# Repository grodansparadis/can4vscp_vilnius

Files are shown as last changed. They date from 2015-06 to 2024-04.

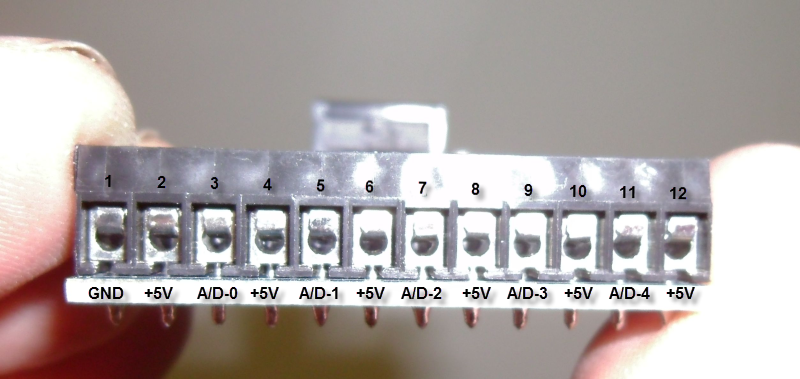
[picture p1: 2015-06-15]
manual/images/termination_block.png

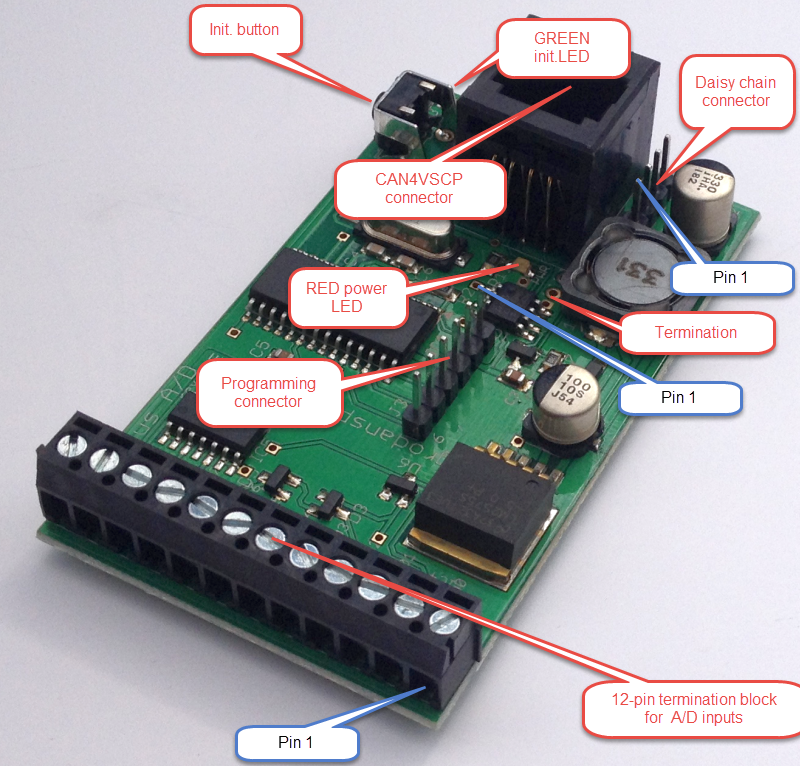
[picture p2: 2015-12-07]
images/vilnius_components.png

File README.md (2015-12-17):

<h1>Vilnius A/D module</h1>



Vilnius A/D module is a CAN4VSCP based module that have four 10-bit A/D channels for 0-5V or 0-10V and also have two 5V I/O channels that can be set as inputs or outputs. General use is to read analog values and as all other VSCP modules you can get the readings reported automatically with a user specified period.

It is also possible to report A/D readings as a VSCP measurement linearized as a floating point value from the formula

measurement = k * A/D-value + m

where k and m are configurable 32-bit floating point constants. You have full control of which event is sent and which unit is used.

This means you can send out any A/D reading as a real unit such as voltage, temperature or in any other SI specified unit.

You can also assign alarm limits so that alarm events are sent when the level goes above a certain value or below a certain value.

Two I/O channels are available. Both can individually be set as inputs or outputs. ON/OFF or TurnOn/TurnOff events can be sent out when I/O change state.

The module can be attached to a standard DIN Rail or be mounted directly on a wall. The mounting enclosures are ordered as separate options when the module is ordered.

The module fully adopts to the VSCP CAN4VSCP specification and can be powered directly over the bus cable with a good 9-28V DC power source. This means there is no need for a separate power cable. VSCP CAN modules are designed to work on a VSCP4CAN bus which use ordinary RJ-45 connectors or use the daisy chain pinhead which can be used to connect modules that are mounted close to each other. For the bus a CAT5 or better twisted pair cable is used. Bus length can have a total length of 500 meters with drops of maximum 24 meters length (up to a total of 120 meters). As for all VSCP4CAN modules the communication speed is fixed at 125 kbps.

All VSCP modules contains information of there own setup, manual, hardware version, manufacturer etc. When VSCP modules are started up they have a default functionality that often is all that is needed to get a working setup. If the module have something to report it will send you an event and if it is setup to react on a certain type of event it will do it's work when you send event(s) to it. It does not need to be harder then that. 

<hr>

This project is part of the <a href="http://www.vscp.org">VSCP (Very Simple Control Protocol) project</a>. 

<hr>

This project is licensed under the 
<a href="http://creativecommons.org/licenses/by-nc-sa/3.0/">Creative Commons open source license Attribution-NonCommercial-ShareAlike 3.0 Unported</a>. 
Other license options are available by conacting <a href="malto:info@grodansparadis.com">Paradis of the Frog AB</a>

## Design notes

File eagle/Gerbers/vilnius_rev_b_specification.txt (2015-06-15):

Ake Hedman
Grodans Paradis AB

Date:				2014-06-18
Part Number: 		Vilnius
Number of boards: 	120
Number of layers: 	2 
Material: 			FR4
Final Thickness:	1.6 mm
Final copper:		1/1oz
Surface treatment: 	ENIG
Unit Size:			72 x 42 mm
Panel Size:			154*126 mm
Unit/panel:			6
Solder Mask:		Green
Silk Screen: 		White	
Outline Profile:	CNC Routing + V-cut
X-out Allowed:		1
Stencil needed:		yes
Gerber layer for Stencil: Component Cream (pmc)

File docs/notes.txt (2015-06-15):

Vilnius notes
=============

Registers
=========
00	Zone
01	Subzone
02	Control register A/D 0
		Bit 0 - Enable
		Bit 1 - Enable event when above level
		Bit 2 - Enable event when below level
		Bit 3 - 
		Bit 4 - 
		Bit 5 - 
		Bit 6 -
		Bit 7 -  	
03	Control register A/D 1
04	Control register A/D 2
05	Control register A/D 3
06	Control register A/D 4

07	Level high for channel 0 MSB   (0-10V * 10000)
08	Level high for channel 0 LSB
09	Level high for channel 1 MSB
0A	Level high for channel 1 LSB
0B	Level high for channel 2 MSB
0C	Level high for channel 2 LSB
0D	Level high for channel 3 MSB
0E	Level high for channel 3 LSB
0F	Level high for channel 4 MSB
10	Level high for channel 5 LSB

11	Level low for channel 0 MSB   (0-10V * 10000)
12	Level low for channel 0 LSB
13	Level low for channel 1 MSB
14	Level low for channel 1 LSB
15	Level low for channel 2 MSB
16	Level low for channel 2 LSB
17	Level low for channel 3 MSB
18	Level low for channel 3 LSB
19	Level low for channel 4 MSB
1A	Level low for channel 5 LSB

1B	Absolute low for channel 0 MSB   (0-10V * 10000)
1C	Absolute low for channel 0 LSB
1D	Absolute low for channel 1 MSB
1E	Absolute low for channel 1 LSB
1F	Absolute low for channel 2 MSB
20	Absolute low for channel 2 LSB
21	Absolute low for channel 3 MSB
22	Absolute low for channel 3 LSB
23	Absolute low for channel 4 MSB
24	Absolute low for channel 5 LSB

25	Absolute high for channel 0 MSB   (0-10V * 10000)
26	Absolute high for channel 0 LSB
27	Absolute high for channel 1 MSB
28	Absolute high for channel 1 LSB
29	Absolute high for channel 2 MSB
2A	Absolute high for channel 2 LSB
2B	Absolute high for channel 3 MSB
2C	Absolute high for channel 3 LSB
2D	Absolute high for channel 4 MSB
2E	Absolute high for channel 5 LSB

A/D stream frequency
Event above level
Event below level
hysteresis.

Actions
=======
0	NOOP
1	Send state. (for sync)

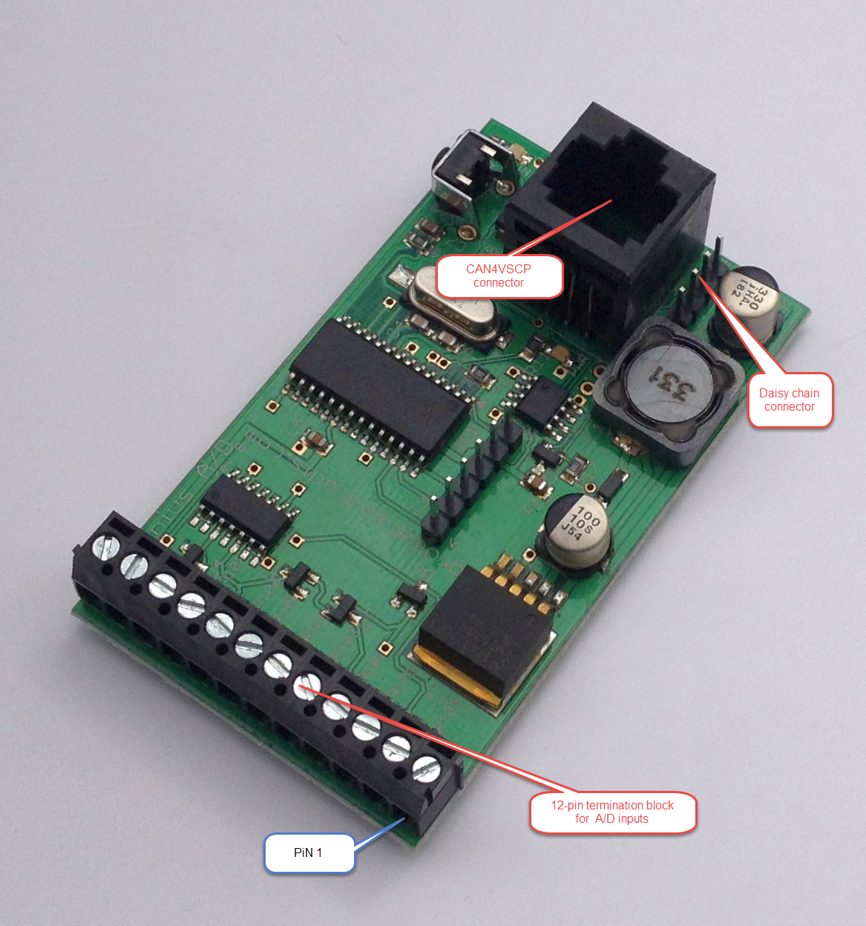
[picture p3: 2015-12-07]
images/vilnius_connectors.png

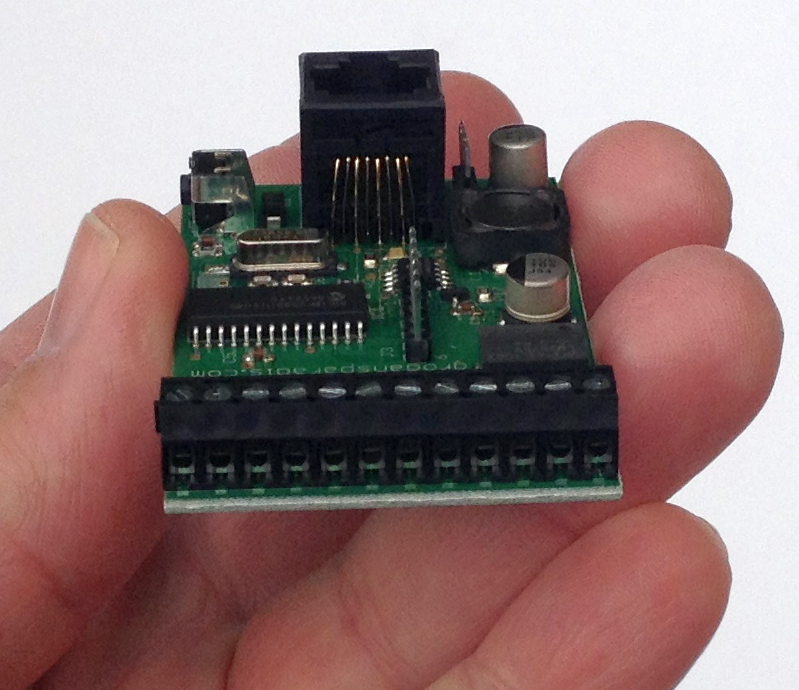
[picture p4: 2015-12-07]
images/vilnius13.png

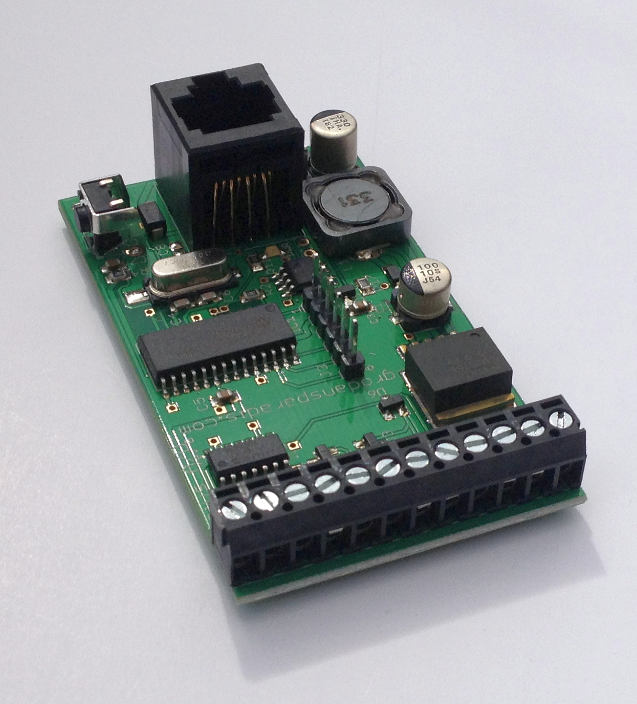
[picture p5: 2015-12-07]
images/vilnius3.png

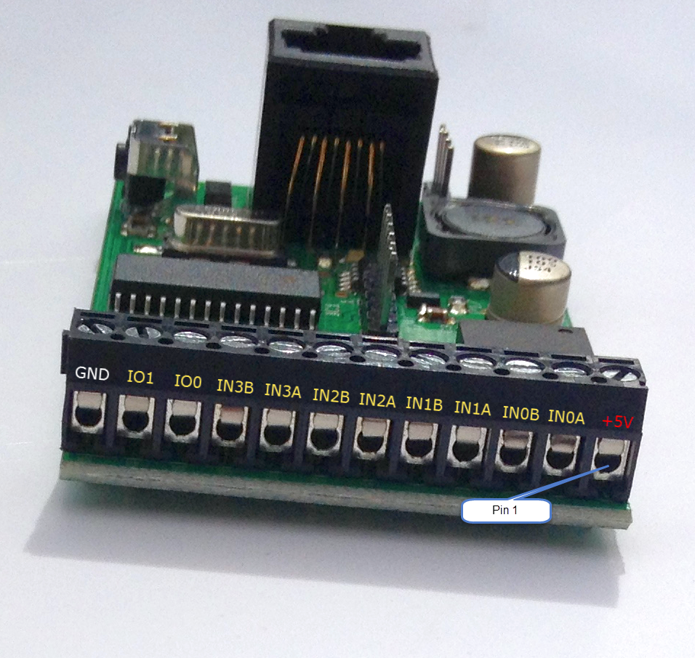
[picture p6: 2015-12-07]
images/vilnius_termination_block.png

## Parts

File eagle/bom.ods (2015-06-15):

Partlis | t exported from | C:/Users/akhe/Docu | ments/develop | ment/hardware_zeus/can4vscp/vilnius_Analog2Digita | l/eagle/vilnius_rev_a.s | ch at 201 | 1-10-04 12:57:53
Part | Value | Device | Package | Description | Description | Supplier | Partnumber | Price
1N5819 | S1D | DIODE-SMB | SMB | DIODE | Protection diod | Digikey | 1N5819HW-FDICT-ND | 3,84
C1 | 100uF | CPOL-EUD | PANASONIC_D | POLARIZED CAPACITOR, European symbol | Elektrolytkondensator | Digikey | PCE3951CT-ND | 5,04
C2 | 330uF | CPOL-EUD | PANASONIC_D | POLARIZED CAPACITOR, European symbol | Elektrolytkondensator | Digikey | PCE4164CT-ND | 4,4
C3 | 100nF | CNP-0805 | 805 | NON-POLARIZED CAP | Avstörningskondensator | Bejoken | 522526 | 0,07
C4 | 15pF | C-EUC0805 | C0805 | CAPACITOR, European symbol | Kondensator | Bejoken | 522419 | 0,11
C5 | 0.1uF | C-EUC0805 | C0805 | CAPACITOR, European symbol | Avstörningskondensator | Bejoken | 522526 | 0,07
C6 | 15pF | C-EUC0805 | C0805 | CAPACITOR, European symbol | Kondensator | Bejoken | 522419 | 0,11
C7 | 0.1uF | C-EUC0805 | C0805 | CAPACITOR, European symbol | Avstörningskondensator | Bejoken | 522526 | 0,07
D1 | S1D | DIODE-SMB | SMB | DIODE | Protection diod | Digikey | 1N5819HW-FDICT-ND | 3,84
D2 | NUP2105L | DIODE-2CA|ACSOT23 | SOT23@1 | Dual DIODE Cathode-Anode|Anode-Cathode | Tansient protection | Digikey | NUP2105LT1GOSCT-ND | 4
D3 | BAT54 | BAV199 | SOT23 | DIODE | Skyddsdiod | Bejoken | 177820 | 0,75
D4 | BAT54 | BAV199 | SOT23 | DIODE | Skyddsdiod | Bejoken | 177820 | 0,75
D5 | BAT54 | BAV199 | SOT23 | DIODE | Skyddsdiod | Bejoken | 177820 | 0,75
D6 | BAT54 | BAV199 | SOT23 | DIODE | Skyddsdiod | Bejoken | 177820 | 0,75
IC1 | PIC18F2580 | PIC18LF252-I/SO | SO28 | 18F252, 28 pin, 32Kb prog, 1536 data, 256 EEPROM | Processor | Digikey | PIC18F2580-I/SO-ND | 60,96
IC3 | MCP2551SN | MCP2551SN | SO-08 | High Speed CAN tranceiver | CAN tranceiver | Digikey | MCP2551-I/SN-ND | 8,96
IC4 | LM2575S | LM2575S | TO263-5 | National Semiconductor 1.0A "Simple Switcher"(c) | Simpleswitcher | Digikey | LM2575S-3.3/NOPB-ND | 23,76
IC5 | MCP604 | 4AMP_P4+11D | SO14 | OP AMP | Opamp | Digikey | MCP6044-I/SL-ND | 11,14
J1 | OSTTE-12 | OSTTE-12 | PINHEAD-12 |  | Terminal Block ' 12 | Digikey | ED2737-nd | 11,68
J2 | A00-108-220-450 | A00-108-220-450 | RJ-45 |  | RJ-45 connector | Digikey | 151-1099-nd | 5,6
J3 |  | MA06-1 | MA06-1 | PIN HEADER | Enkel stiftlist | Digikey | SAM1035-50-ND | 0,33
J4 |  | MA04-1 | MA04-1 | PIN HEADER | Enkel stiftlist | Digikey | SAM1035-50-ND | 0,33
L1 | 330 uH | DO3316P | DO3316P | COILCRAFT | Drossel 330u | Digikey | 553-1514-1-nd | 10,24
LED1 |  | LEDCHIP-LED0805 | CHIP-LED0805 | LED | Green LED | Digikey | 475-1410-1-nd | 0,88
LED9 |  | LEDCHIP-LED0805 | CHIP-LED0805 | LED | Green LED | Digikey | 475-1410-1-nd | 0,88
Q1 | 10 MHz | HC-49S | 9C | Digikey 887-1050-1-nd | 10 MHz Crystal | Digikey | 887-1050-1-d | 4,24
R2 | 10K | R-EU_R0805 | R0805 | RESISTOR, European symbol | Resistor | Bejoken | 454676 | 0,01
R3 | 1K | R-EU_R0805 | R0805 | RESISTOR, European symbol | Resistor | Bejoken | 454650 | 0,01
R4 | 10K | R-EU_R0805 | R0805 | RESISTOR, European symbol | Resistor | Bejoken | 454676 | 0,01
R11 | 1K | R-EU_R0805 | R0805 | RESISTOR, European symbol | Resistor | Bejoken | 454650 | 0,01
R100 | 10K | R-EU_R0805 | R0805 | RESISTOR, European symbol | Resistor | Bejoken | 454676 | 0,01
R101 | 10K | R-EU_R0805 | R0805 | RESISTOR, European symbol | Resistor | Bejoken | 454676 | 0,01
R102 | 10K | R-EU_R0805 | R0805 | RESISTOR, European symbol | Resistor | Bejoken | 454676 | 0,01
R103 | 10K | R-EU_R0805 | R0805 | RESISTOR, European symbol | Resistor | Bejoken | 454676 | 0,01
R104 | 10K | R-EU_R0805 | R0805 | RESISTOR, European symbol | Resistor | Bejoken | 454676 | 0,01
R105 | 10K | R-EU_R0805 | R0805 | RESISTOR, European symbol | Resistor | Bejoken | 454676 | 0,01
R106 | 10K | R-EU_R0805 | R0805 | RESISTOR, European symbol | Resistor | Bejoken | 454676 | 0,01
R107 | 10K | R-EU_R0805 | R0805 | RESISTOR, European symbol | Resistor | Bejoken | 454676 | 0,01
S1 |  | 31-XX | B3F-31XX | OMRON SWITCH | Init switch | Elfa | 35-677-65 | 2,89
 |  |  |  |  |  |  |  | 166,56

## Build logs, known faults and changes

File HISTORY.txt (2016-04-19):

Vilnius A/D converter module
============================

2016-04-19 AKHE - RA4 set to input to prevent collision with VCAP circuits in
                  PIC18F2580. Brown out raised to maximum (3V & 4.6V). Valuable                    input from Anders Forsgren, AJE Electronics AB.
2016-04-11 AKHE - vscp_getMatrixInfo nw use the pointer supplied by the framework.
2016-04-04 AKHE - Changed value of C14 to 10uF
2016-03-23 AKHE - Version 1.0.3------------------------------------------------
2016-03-23 AKHE - Adopter to VSCP firmware 1.6.1
2016-03-08 AKHE - Adopted to 1.6 firmware. Adopted for PIC18F26K80.
2015-11-15 AKHE - Started development

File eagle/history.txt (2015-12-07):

Vilnius
=======

2015-12-07 - AKHE Added missing power and ground on IC5.
2015-12-07 - AKHE Named ports.
2015-11-14 - AKHE VCAP decoupled from VCC
2015-11-14 - Rev C
2014-06-19 - AKHE Fixed dimensions
2014-06-18 - AKHE Away to factory
2013-06-04 - AKHE Added power to missing pin 6 capacitor.
2011-12-20 - AKHE Added termination resistor. Leave unpopulated.
2011-11-17 - AKHE Added 1uF capacitor on uP pin 6 forPIC18F66K80 compatibility
2011-11-15 - AKHE Move L1 so it fits on the board.
2011-11-10 - AKHE Packages for D1/D2 updatet to SOD123 from SMDB
2011-11-10 - AKHE CANH should be on pin 4 of RJ-45
2011-11-02 - AKHE Kontaktlist uppdaterad. Hål var 0.9 och för trånga. Nu 1.2 istället.

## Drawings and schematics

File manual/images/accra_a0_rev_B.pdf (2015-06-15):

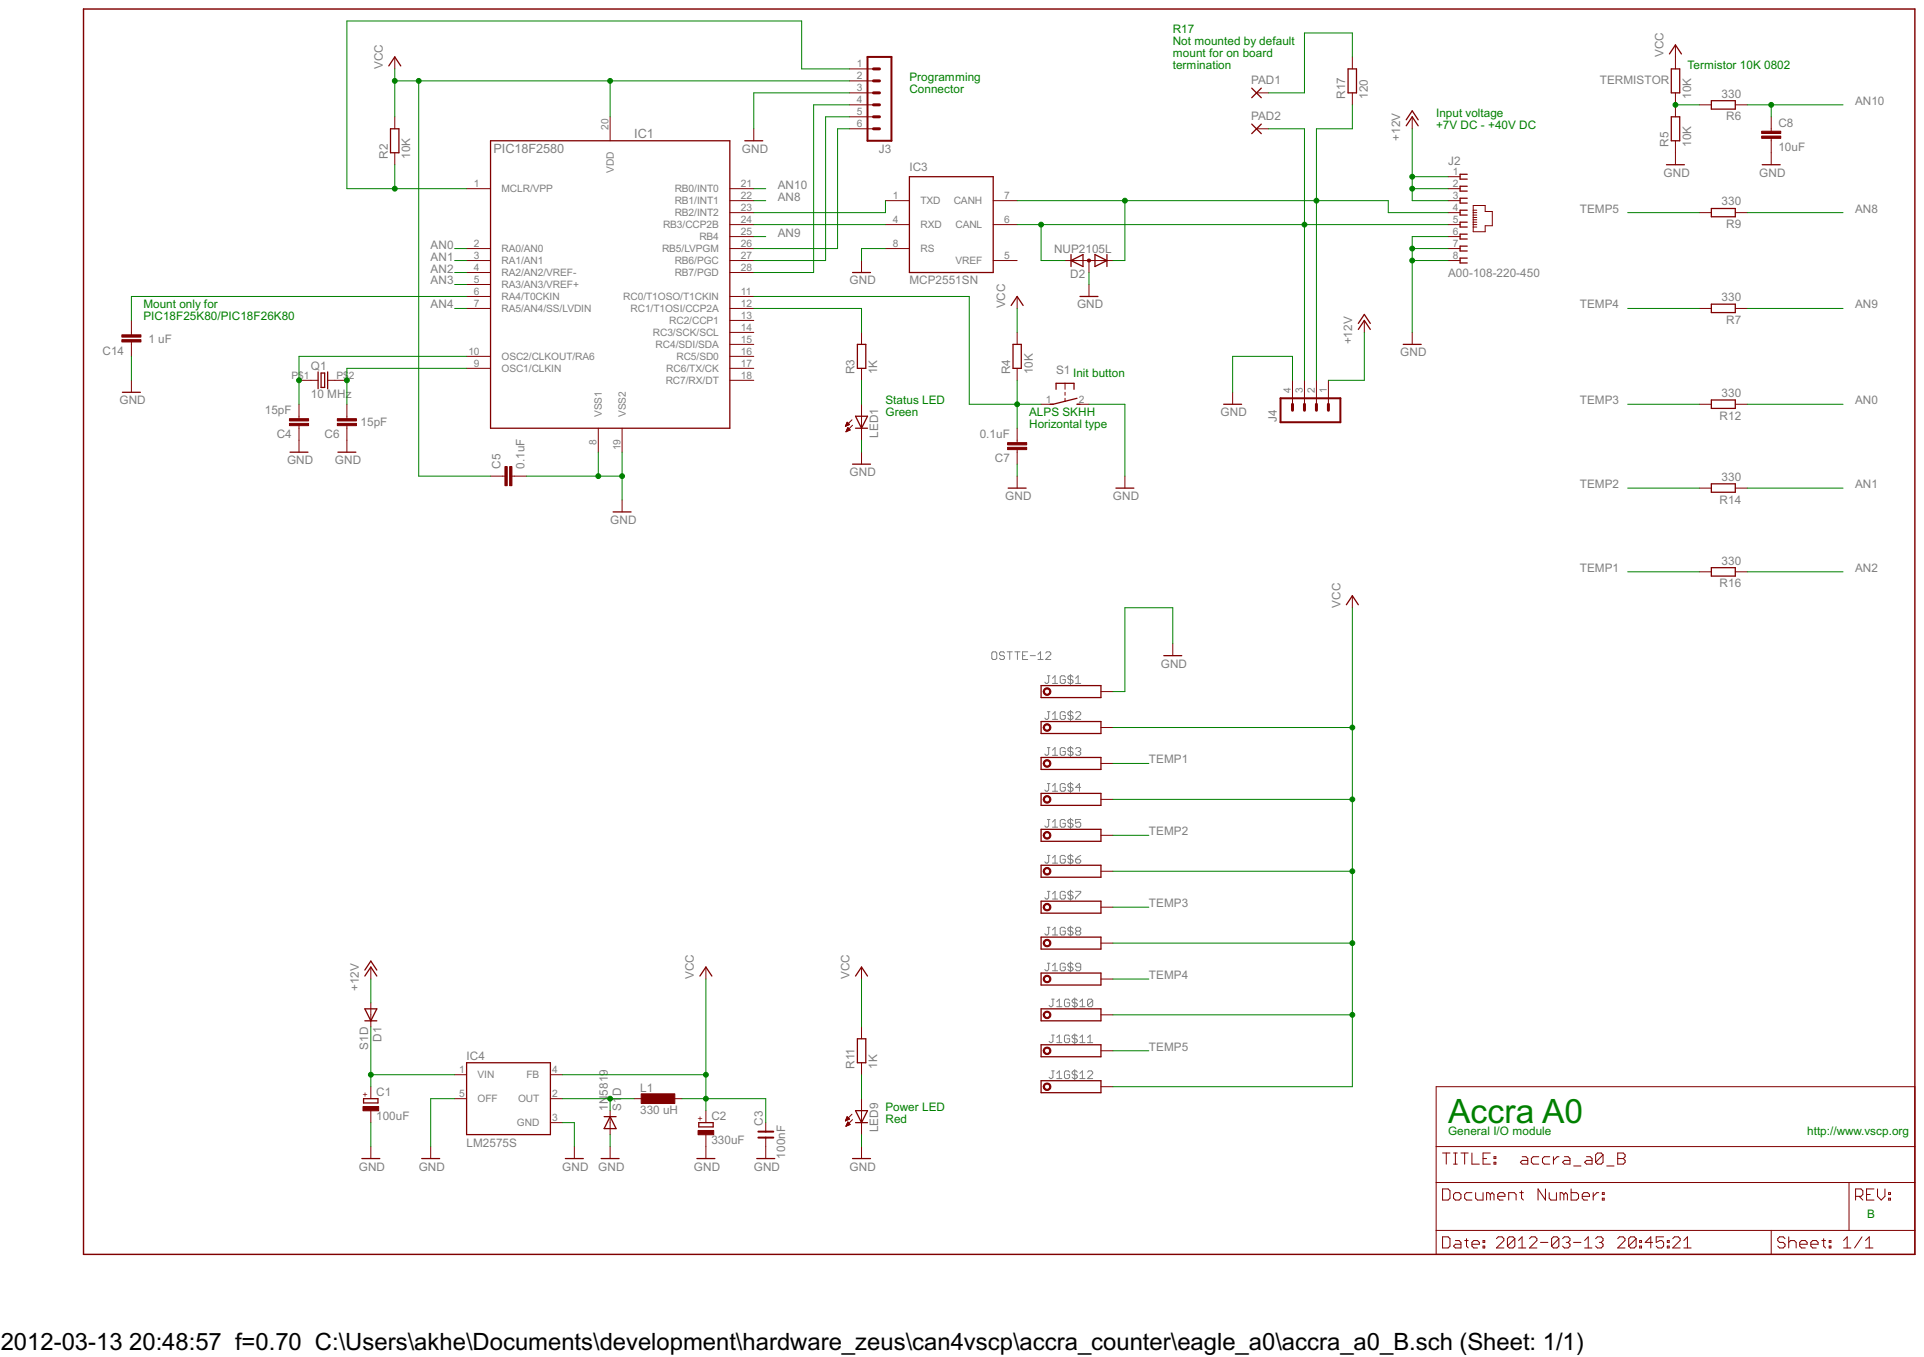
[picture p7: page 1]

termination R17
Not mounted by default mount for on board

Input voltage +7V DC - +40V DC

Init button Status LED

2012-03-13 20:48:57 f=0.70 C:\Users\akhe\Documents\development\hardware_zeus\can4vscp\accra_counter\eagle_a0\accra_a0_B.sch (Sheet: 1/1)

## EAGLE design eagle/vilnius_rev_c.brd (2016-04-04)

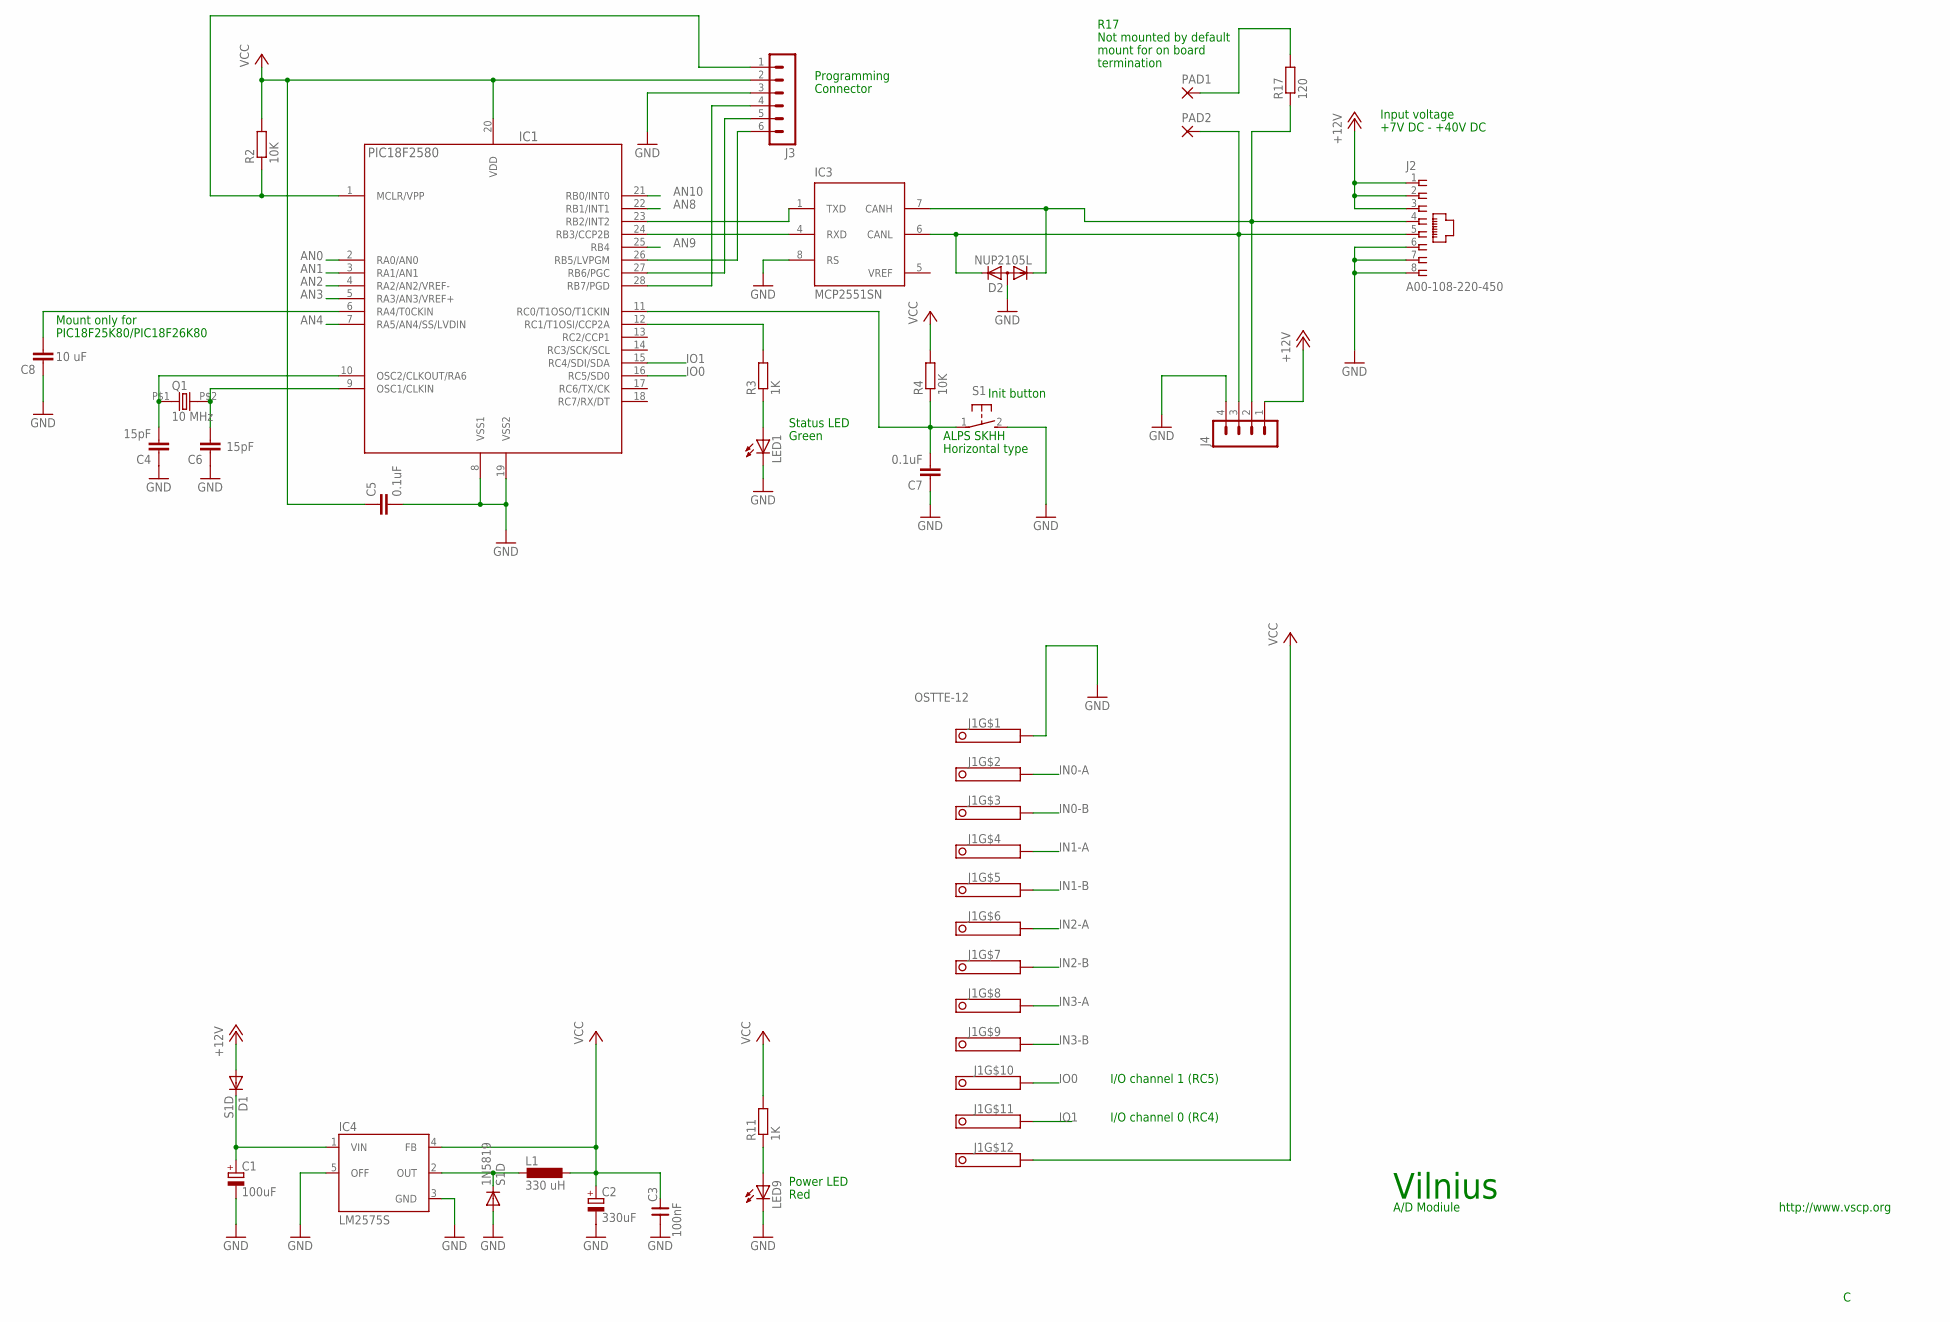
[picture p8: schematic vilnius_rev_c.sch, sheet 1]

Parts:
1N5819: S1D; SOD123
C1: 100uF; PANASONIC_D
C2: 330uF; PANASONIC_D
C3: 100nF; 0805
C4, C6: 15pF; C0805
C5, C7: 0.1uF; C0805
C8: 10 uF; C0805
D1: S1D; SOD123
D2: NUP2105L; SOT23@1
IC1: PIC18F2580; SO28
IC3: MCP2551SN; SO-08
IC4: LM2575S; TO263-5
J1: OSTTE-12; PINHEAD-12
J2: A00-108-220-450; RJ-45
J3: MA06-1
J4: MA04-1
L1: 330 uH; DO3316P
LED1, LED9: LEDCHIP-LED0805; CHIP-LED0805
PAD1, PAD2: 1,6/0,8
Q1: 10 MHz; 9C
R2, R4: 10K; R0805
R3, R11: 1K; R0805
R17: 120; R0805
S1: 31-XX; B3F-31XX

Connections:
+12V: D1.A, J2.1, J2.2, J2.3, J4.1
AN0: IC1.2 (RA0/AN0); also elsewhere on the board
AN1: IC1.3 (RA1/AN1); also elsewhere on the board
AN2: IC1.4 (RA2/AN2/VREF-); also elsewhere on the board
AN3: IC1.5 (RA3/AN3/VREF+); also elsewhere on the board
AN4: IC1.7 (RA5/AN4/SS/LVDIN)
AN8: IC1.22 (RB1/INT1)
AN9: IC1.25 (RB4)
AN10: IC1.21 (RB0/INT0)
CANL: D2.2 (K2), IC3.6 (CANL), J2.5, J4.3, PAD2.1
GND: 1N5819.A, C1.-, C2.-, C3.1, C4.1, C5.2, C6.1, C7.1, C8.1, D2.3 (A), IC1.8 (VSS1), IC1.19 (VSS2), IC3.2 (VSS), IC3.8 (RS), IC4.3 (GND), IC4.5 (OFF), J1.1, J2.6, J2.7, J2.8, J3.3, J4.4, LED1.C, LED9.C, S1.2 (S); also elsewhere on the board
IN0-A: J1.2; also elsewhere on the board
IN0-B: J1.3; also elsewhere on the board
IN1-A: J1.4; also elsewhere on the board
IN1-B: J1.5; also elsewhere on the board
IN2-A: J1.6; also elsewhere on the board
IN2-B: J1.7; also elsewhere on the board
IN3-A: J1.8; also elsewhere on the board
IN3-B: J1.9; also elsewhere on the board
IO0: IC1.16 (RC5/SD0), J1.10
IO1: IC1.15 (RC4/SDI/SDA), J1.11
unnamed: 1N5819.C, IC4.2 (OUT), L1.1
unnamed: C4.2, IC1.10 (OSC2/CLKOUT/RA6), Q1.P$1 (1)
unnamed: C1.+, D1.C, IC4.1 (VIN)
unnamed: IC1.12 (RC1/T1OSI/CCP2A), R3.2
unnamed: LED1.A, R3.1
unnamed: C7.2, IC1.11 (RC0/T1OSO/T1CKIN), R4.1, S1.1
unnamed: C6.2, IC1.9 (OSC1/CLKIN), Q1.P$2 (2)
unnamed: C8.2, IC1.6 (RA4/T0CKIN)
unnamed: PAD1.1, R17.2
unnamed: IC1.1 (MCLR/VPP), J3.1, R2.1
unnamed: IC1.28 (RB7/PGD), J3.4
unnamed: IC1.27 (RB6/PGC), J3.5
unnamed: IC1.26 (RB5/LVPGM), J3.6
unnamed: LED9.A, R11.1
unnamed: D2.1 (K1), IC3.7 (CANH), J2.4, J4.2, R17.1
RXCAN: IC1.24 (RB3/CCP2B), IC3.4 (RXD)
TXCAN: IC1.23 (RB2/INT2), IC3.1 (TXD)
VCC: C2.+, C3.2, C5.1, IC1.20 (VDD), IC3.3 (VDD), IC4.4 (FB), J1.12, J3.2, L1.2, R2.2, R4.2, R11.2; also elsewhere on the board
VREF: IC3.5 (VREF)

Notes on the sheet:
Init button
Status LED
Programming
Connector
ALPS SKHH
Horizontal type
Vilnius
http://www.vscp.org
A/D Modiule
Input voltage
+7V DC - +40V DC
Power LED
Red
Green
Mount only for
PIC18F25K80/PIC18F26K80
Not mounted by default
mount for on board
termination
R17
I/O channel 0 (RC4)
I/O channel 1 (RC5)

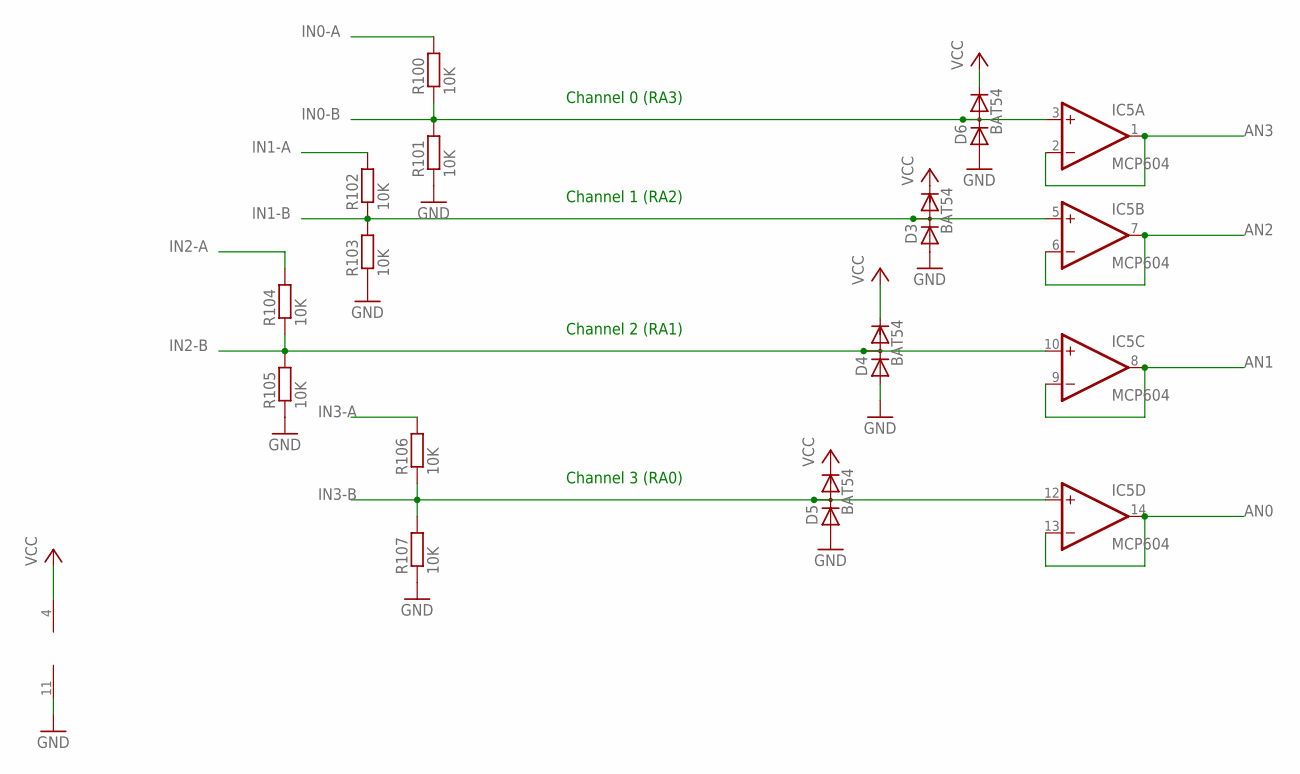
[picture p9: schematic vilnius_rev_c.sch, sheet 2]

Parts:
D3, D4, D5, D6: BAT54; SOT23
IC5: MCP604; SO14
R100, R101, R102, R103, R104, R105, R106, R107: 10K; R0805

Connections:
AN0: IC5.13 (-IN), IC5.14 (OUT); also elsewhere on the board
AN1: IC5.8 (OUT), IC5.9 (-IN); also elsewhere on the board
AN2: IC5.6 (-IN), IC5.7 (OUT); also elsewhere on the board
AN3: IC5.1 (OUT), IC5.2 (-IN); also elsewhere on the board
GND: D3.1 (A), D4.1 (A), D5.1 (A), D6.1 (A), IC5.11 (V-), R101.1, R103.1, R105.1, R107.1; also elsewhere on the board
IN0-A: R100.2; also elsewhere on the board
IN0-B: D6.3 (AC), IC5.3 (+IN), R100.1, R101.2; also elsewhere on the board
IN1-A: R102.2; also elsewhere on the board
IN1-B: D3.3 (AC), IC5.5 (+IN), R102.1, R103.2; also elsewhere on the board
IN2-A: R104.2; also elsewhere on the board
IN2-B: D4.3 (AC), IC5.10 (+IN), R104.1, R105.2; also elsewhere on the board
IN3-A: R106.2; also elsewhere on the board
IN3-B: D5.3 (AC), IC5.12 (+IN), R106.1, R107.2; also elsewhere on the board
VCC: D3.2 (C), D4.2 (C), D5.2 (C), D6.2 (C), IC5.4 (V+); also elsewhere on the board

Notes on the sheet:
Channel 0 (RA3)
Channel 1 (RA2)
Channel 2 (RA1)
Channel 3 (RA0)

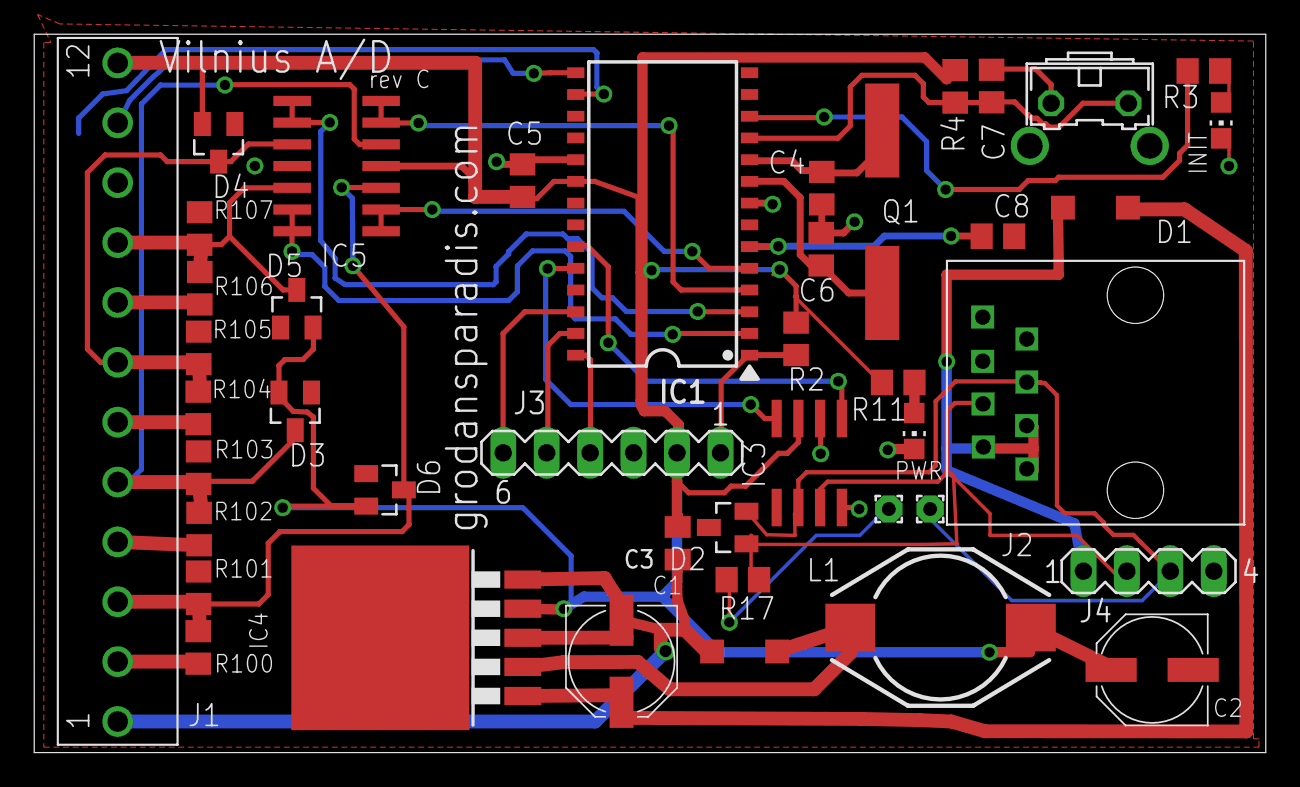
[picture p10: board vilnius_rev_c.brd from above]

Board: 2 copper layers, 72.0 x 42.0 mm, 43 parts (0 on the bottom side), 35 nets.

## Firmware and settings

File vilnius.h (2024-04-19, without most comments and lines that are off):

#define VILNIUS_H
#define	TRUE                    1
#define	FALSE                   0
#define MODULE_VOLTAGE          5.0
#define MODULE_AD_MAX_VALUE     1023    // 10-bit
#define TIMER0_RELOAD_VALUE		0xfb1d
#define TIMER2_RELOAD_VALUE		156
#define SELECT_ADC0             (0<<2)  // ADC0
#define SELECT_ADC1             (1<<2)  // ADC1
#define SELECT_ADC2             (2<<2)  // ADC2
#define SELECT_ADC3             (3<<2)  // ADC3
#define STATUS_LED              PORTCbits.RC1
#define INIT_BUTTON             PORTCbits.RC0
#define CHANNEL0                PORTAbits.RA3
#define CHANNEL1                PORTAbits.RA3
#define CHANNEL2                PORTAbits.RA1
#define CHANNEL3                PORTAbits.RA0
#define IO0_INPUT               PORTCbits.RC5
#define IO1_INPUT               PORTCbits.RC4
#define IO0_OUTPUT              LATCbits.LATC5
#define IO1_OUTPUT              LATCbits.LATC4
#define IO0_DIR                 TRISC5
#define IO1_DIR                 TRISC4
#define DEFAULT_VILNIUS_CONTROL_MODULE                  0
#define DEFAULT_VILNIUS_CONTROL_CHANNEL0                0x00
#define DEFAULT_VILNIUS_CONTROL_CHANNEL1                0x00
#define DEFAULT_VILNIUS_CONTROL_CHANNEL2                0x00
#define DEFAULT_VILNIUS_CONTROL_CHANNEL3                0x00
#define DEFAULT_AD0_HYSTERESIS                          200
#define DEFAULT_AD1_HYSTERESIS                          200
#define DEFAULT_AD2_HYSTERESIS                          200
#define DEFAULT_AD3_HYSTERESIS                          200
#define DEFAULT_AD0_REPORT_INTERVAL                     0
#define DEFAULT_AD1_REPORT_INTERVAL                     0
#define DEFAULT_AD2_REPORT_INTERVAL                     0
#define DEFAULT_AD3_REPORT_INTERVAL                     0
#define DEFAULT_MEASUREMENT0_REPORT_INTERVAL_MSB        0
#define DEFAULT_MEASUREMENT0_REPORT_INTERVAL_LSB        0
#define DEFAULT_MEASUREMENT1_REPORT_INTERVAL_MSB        0
#define DEFAULT_MEASUREMENT1_REPORT_INTERVAL_LSB        0
#define DEFAULT_MEASUREMENT2_REPORT_INTERVAL_MSB        0
#define DEFAULT_MEASUREMENT2_REPORT_INTERVAL_LSB        0
#define DEFAULT_MEASUREMENT3_REPORT_INTERVAL_MSB        0
#define DEFAULT_MEASUREMENT3_REPORT_INTERVAL_LSB        0
#define DEFAULT_IO_CONTROL                              0
#define DEFAULT_LINEARIZATION_EVENT_SETTING             0
#define DEFAULT_LINEARIZATION_EVENT_CLASS               10
#define DEFAULT_LINEARIZATION_EVENT_TYPE                16
#define VSCP_ALARM_LOW                                  0x00000001
#define VSCP_ALARM_HIGH                                 0x00000010
#define CONFIG_AD_LOW_ALARM_ENABLE                      0b00000010
#define CONFIG_AD_HIGH_ALARM_ENABLE                     0b00000100
#define CONFIG_AD_USE_A_INPUT                           0b00001000
#define CONFIG_IO0_DIRECTION                            0b00000001  // 0=output, 1=input
#define CONFIG_IO1_DIRECTION                            0b00000010  // 0=output, 1=input
#define CONFIG_IO0_EVENT_ON_CHANGE                      0b00010000
#define CONFIG_IO1_EVENT_ON_CHANGE                      0b00100000
#define CONFIG_IO0_EVENT_SELECT                         0b01000000
#define CONFIG_IO1_EVENT_SELECT                         0b10000000
#define CONFIG_MEASUREMENT_UNIT_POS                     0b00001000
#define MEASUREMENT_CTRL_CLASS_BIT_8                    0b01000000
#define MEASUREMENT_CTRL_UNIT_MASK                      0b00011000
#define REG0_VILNIUS_ZONE                               0
#define REG0_VILNIUS_SUBZONE                            1
#define REG0_VILNIUS_CH0_ZONE                           2
#define REG0_VILNIUS_CH0_SUBZONE                        3
#define REG0_VILNIUS_CH1_ZONE                           4
#define REG0_VILNIUS_CH1_SUBZONE                        5
#define REG0_VILNIUS_CH2_ZONE                           6
#define REG0_VILNIUS_CH2_SUBZONE                        7
#define REG0_VILNIUS_CH3_ZONE                           8
#define REG0_VILNIUS_CH3_SUBZONE                        9
#define REG0_VILNIUS_IO0_ZONE                           10
#define REG0_VILNIUS_IO0_SUBZONE                        11
#define REG0_VILNIUS_IO1_ZONE                           12
#define REG0_VILNIUS_IO1_SUBZONE                        13
#define REG0_VILNIUS_CONTROL_MODULE                     14
#define REG0_VILNIUS_CONTROL_CHANNEL0                   15
#define REG0_VILNIUS_CONTROL_CHANNEL1                   16
#define REG0_VILNIUS_CONTROL_CHANNEL2                   17
#define REG0_VILNIUS_CONTROL_CHANNEL3                   18
#define REG0_VILNIUS_AD_VALUE_CHANNEL0_MSB              19
#define REG0_VILNIUS_AD_VALUE_CHANNEL0_LSB              20
#define REG0_VILNIUS_AD_VALUE_CHANNEL1_MSB              21
#define REG0_VILNIUS_AD_VALUE_CHANNEL1_LSB              22
#define REG0_VILNIUS_AD_VALUE_CHANNEL2_MSB              23
#define REG0_VILNIUS_AD_VALUE_CHANNEL2_LSB              24
#define REG0_VILNIUS_AD_VALUE_CHANNEL3_MSB              25
#define REG0_VILNIUS_AD_VALUE_CHANNEL3_LSB              26
#define REG0_VILNIUS_AD_REPORT_INTERVAL_CHANNEL0_MSB    27
#define REG0_VILNIUS_AD_REPORT_INTERVAL_CHANNEL0_LSB    28
#define REG0_VILNIUS_AD_REPORT_INTERVAL_CHANNEL1_MSB    29
#define REG0_VILNIUS_AD_REPORT_INTERVAL_CHANNEL1_LSB    30
#define REG0_VILNIUS_AD_REPORT_INTERVAL_CHANNEL2_MSB    31
#define REG0_VILNIUS_AD_REPORT_INTERVAL_CHANNEL2_LSB    32
#define REG0_VILNIUS_AD_REPORT_INTERVAL_CHANNEL3_MSB    33
#define REG0_VILNIUS_AD_REPORT_INTERVAL_CHANNEL3_LSB    34
#define REG0_VILNIUS_ALARM_LOW_CHANNEL0_MSB             35
#define REG0_VILNIUS_ALARM_LOW_CHANNEL0_LSB             36
#define REG0_VILNIUS_ALARM_LOW_CHANNEL1_MSB             37
#define REG0_VILNIUS_ALARM_LOW_CHANNEL1_LSB             38
#define REG0_VILNIUS_ALARM_LOW_CHANNEL2_MSB             39
#define REG0_VILNIUS_ALARM_LOW_CHANNEL2_LSB             40
#define REG0_VILNIUS_ALARM_LOW_CHANNEL3_MSB             41
#define REG0_VILNIUS_ALARM_LOW_CHANNEL3_LSB             42
#define REG0_VILNIUS_ALARM_HIGH_CHANNEL0_MSB            43
#define REG0_VILNIUS_ALARM_HIGH_CHANNEL0_LSB            44
#define REG0_VILNIUS_ALARM_HIGH_CHANNEL1_MSB            45
#define REG0_VILNIUS_ALARM_HIGH_CHANNEL1_LSB            46
#define REG0_VILNIUS_ALARM_HIGH_CHANNEL2_MSB            47
#define REG0_VILNIUS_ALARM_HIGH_CHANNEL2_LSB            48
#define REG0_VILNIUS_ALARM_HIGH_CHANNEL3_MSB            49
#define REG0_VILNIUS_ALARM_HIGH_CHANNEL3_LSB            50
#define REG0_VILNIUS_HYSTERESIS_CH0_MSB                 51
#define REG0_VILNIUS_HYSTERESIS_CH1_MSB                 52
#define REG0_VILNIUS_HYSTERESIS_CH2_MSB                 53
#define REG0_VILNIUS_HYSTERESIS_CH3_MSB                 54
#define REG0_VILNIUS_MEASUREMENT_REPORT_INTERVAL_CH0_MSB    55
#define REG0_VILNIUS_MEASUREMENT_REPORT_INTERVAL_CH0_LSB    56
#define REG0_VILNIUS_MEASUREMENT_REPORT_INTERVAL_CH1_MSB    57
#define REG0_VILNIUS_MEASUREMENT_REPORT_INTERVAL_CH1_LSB    58
#define REG0_VILNIUS_MEASUREMENT_REPORT_INTERVAL_CH2_MSB    59
#define REG0_VILNIUS_MEASUREMENT_REPORT_INTERVAL_CH2_LSB    60
#define REG0_VILNIUS_MEASUREMENT_REPORT_INTERVAL_CH3_MSB    61
#define REG0_VILNIUS_MEASUREMENT_REPORT_INTERVAL_CH3_LSB    62
#define REG0_VILNIUS_ABSOLUT_LOW_CHANNEL0_MSB           63
#define REG0_VILNIUS_ABSOLUT_LOW_CHANNEL0_LSB           64
#define REG0_VILNIUS_ABSOLUT_LOW_CHANNEL1_MSB           65
#define REG0_VILNIUS_ABSOLUT_LOW_CHANNEL1_LSB           66
#define REG0_VILNIUS_ABSOLUT_LOW_CHANNEL2_MSB           67
#define REG0_VILNIUS_ABSOLUT_LOW_CHANNEL2_LSB           68
#define REG0_VILNIUS_ABSOLUT_LOW_CHANNEL3_MSB           69
#define REG0_VILNIUS_ABSOLUT_LOW_CHANNEL3_LSB           70
#define REG0_VILNIUS_ABSOLUT_HIGH_CHANNEL0_MSB          71
#define REG0_VILNIUS_ABSOLUT_HIGH_CHANNEL0_LSB          72
#define REG0_VILNIUS_ABSOLUT_HIGH_CHANNEL1_MSB          73
#define REG0_VILNIUS_ABSOLUT_HIGH_CHANNEL1_LSB          74
#define REG0_VILNIUS_ABSOLUT_HIGH_CHANNEL2_MSB          75
#define REG0_VILNIUS_ABSOLUT_HIGH_CHANNEL2_LSB          76
#define REG0_VILNIUS_ABSOLUT_HIGH_CHANNEL3_MSB          77
#define REG0_VILNIUS_ABSOLUT_HIGH_CHANNEL3_LSB          78
#define REG0_VILNIUS_CONTROL_IO                         79
#define REG0_VILNIUS_IO_STATE                           80
#define REG1_VILNIUS_LINEARIZATION_EVENT_SETTING_CH0    0
#define REG1_VILNIUS_LINEARIZATION_EVENT_CLASS_CH0      1
#define REG1_VILNIUS_LINEARIZATION_EVENT_TYPE_CH0       2
#define REG1_VILNIUS_LINEARIZATION_EVENT_SETTING_CH1    3
#define REG1_VILNIUS_LINEARIZATION_EVENT_CLASS_CH1      4
#define REG1_VILNIUS_LINEARIZATION_EVENT_TYPE_CH1       5
#define REG1_VILNIUS_LINEARIZATION_EVENT_SETTING_CH2    6
#define REG1_VILNIUS_LINEARIZATION_EVENT_CLASS_CH2      7
#define REG1_VILNIUS_LINEARIZATION_EVENT_TYPE_CH2       8
#define REG1_VILNIUS_LINEARIZATION_EVENT_SETTING_CH3    9
#define REG1_VILNIUS_LINEARIZATION_EVENT_CLASS_CH3      10
#define REG1_VILNIUS_LINEARIZATION_EVENT_TYPE_CH3       11
#define REG1_VILNIUS_CH0_LINEARIZATION_K_MSB    12
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

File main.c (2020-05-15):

/* ******************************************************************************
 * 	VSCP (Very Simple Control Protocol) 
 * 	http://www.vscp.org
 *
 *  Vilnius A/D module
 *  ==================
 *
 *  Copyright (C) 2015-2020-https://github.com/grodansparadis/can4vscp_paris/releases/download/v1.1.6/paris_relay_pic18f26k80_1_1_6_relocated.hex Ake Hedman, Grodans Paradis AB
 *                          http://www.grodansparadis.com
 *                          <akhe@grodansparadis.com>
 *
 *  This work is licensed under the Creative Common 
 *  Attribution-NonCommercial-ShareAlike 3.0 Unported license. The full
 *  license is available in the top folder of this project (LICENSE) or here
 *  http://creativecommons.org/licenses/by-nc-sa/3.0/legalcode
 *  It is also available in a human readable form here 
 *  http://creativecommons.org/licenses/by-nc-sa/3.0/
 * 
 *	This file is part of VSCP - Very Simple Control Protocol 	
 *	http://www.vscp.org
 *
 * ******************************************************************************
 */

#include "vscp_compiler.h"
#include "vscp_projdefs.h"

#include <xc.h>
#include <timers.h>
#include <delays.h>
#include <inttypes.h>
#include <string.h>
#include <ECAN.h>
#include <vscp-firmware.h>
#include <vscp_class.h>
#include <vscp_type.h>
#include "vilnius.h"
#include "main.h"
#include "version.h"

#if defined(_18F2580) 

#if defined(RELEASE)

#pragma config WDT = ON, WDTPS = 128
#pragma config OSC = HSPLL
#pragma config BOREN = BOACTIVE
#pragma config STVREN = ON
#pragma config BORV = 0             // 4.6V
#pragma config LVP = ON
#pragma config CPB = ON
#pragma config BBSIZ = 2048
#pragma config WRTD  = OFF

#pragma config EBTR0 = OFF
#pragma config EBTR1 = OFF
#pragma config EBTR2 = OFF
#pragma config EBTR3 = OFF

#pragma config EBTRB = OFF

#else

#pragma config WDT = OFF
#pragma config OSC = HSPLL
#pragma config PWRT = ON
#pragma config BOREN = BOACTIVE
#pragma config STVREN = ON
#pragma config BORV = 0             // 4.6V
#pragma config LVP = OFF
#pragma config CPB = OFF
#pragma config WRTD  = OFF

#pragma config EBTR0 = OFF
#pragma config EBTR1 = OFF
#pragma config EBTR2 = OFF
#pragma config EBTR3 = OFF

#pragma config EBTRB = OFF

#endif


#else if defined(_18F25K80) || defined(_18F26K80) || defined(_18F45K80) || defined(_18F46K80) || defined(_18F65K80) || defined(_18F66K80)


// CONFIG1L
#pragma config SOSCSEL = DIG    // RC0/RC is I/O
#pragma config RETEN = OFF      // Ultra low-power regulator is Disabled (Controlled by REGSLP bit).
#pragma config INTOSCSEL = HIGH // LF-INTOSC in High-power mode during Sleep.
#pragma config XINST = OFF      // No extended instruction set

// CONFIG1H
#pragma config FOSC = HS2       // Crystal 10 MHz
#pragma config PLLCFG = ON      // 4 x PLL

// CONFIG2H
#pragma config WDTPS = 1048576  // Watchdog prescaler
#pragma config BOREN = SBORDIS  // Brown out enabled
#pragma config BORV  = 0        // 3V

// CONFIG3H
#pragma config CANMX = PORTB    // ECAN TX and RX pins are located on RB2 and RB3, respectively.
#pragma config MSSPMSK = MSK7   // 7 Bit address masking mode.
#pragma config MCLRE = ON       // MCLR Enabled, RE3 Disabled.

// CONFIG4L
#pragma config STVREN = ON      // Stack Overflow Reset enabled
#pragma config BBSIZ = BB2K     // Boot block size 2K

#ifdef DEBUG
#pragma config WDTEN = OFF      // WDT disabled in hardware; SWDTEN bit disabled.
#else
#pragma config WDTEN = ON       // WDT enabled in hardware; 
#endif


#endif

// Calculate and st required filter and mask
// for the current decision matrix
void calculateSetFilterMask( void );

// The device URL (max 32 characters including null termination)
const uint8_t vscp_deviceURL[] = "www.eurosource.se/vilnius_1.xml";

volatile unsigned long measurement_clock_sec;  // Clock for one second work

uint16_t sendTimer;         // Timer for CAN send
uint8_t seconds;            // Counter for seconds
uint8_t minutes;            // Counter for minutes
uint8_t hours;              // Counter for hours

uint16_t analog_value[4];   // A/D values

// Set to true when an alarm condition is met. Will be reseted
// when alarm condition is not met.
BOOL bLowAlarm[ 4 ];
BOOL bHighAlarm[ 4 ];

// Report interval counters
volatile uint16_t valueReports[ 4 ];
uint16_t measurementReports[ 4 ];

// IO states
BOOL IOsavebit0;
BOOL IOsavebit1;

//__EEPROM_DATA(0x11,0x22,0x33,0x44,0x55,0x66,0x77,0x88);

// This table translates registers in page 0 to EEPROM locations
const uint8_t reg2eeprom_pg0[] = {
    /* REG0_VILNIUS_ZONE                    */          VSCP_EEPROM_END + 0,
    /* REG0_VILNIUS_SUBZONE                 */          VSCP_EEPROM_END + 1,
    /* REG0_VILNIUS_CH0_ZONE                */          VSCP_EEPROM_END + 2,
    /* REG0_VILNIUS_CH0_SUBZONE             */          VSCP_EEPROM_END + 3,
    /* REG0_VILNIUS_CH1_ZONE                */          VSCP_EEPROM_END + 4,
    /* REG0_VILNIUS_CH1_SUBZONE             */          VSCP_EEPROM_END + 5,
    /* REG0_VILNIUS_CH2_ZONE                */          VSCP_EEPROM_END + 6,
    /* REG0_VILNIUS_CH2_SUBZONE             */          VSCP_EEPROM_END + 7,
    /* REG0_VILNIUS_CH3_ZONE                */          VSCP_EEPROM_END + 8,
    /* REG0_VILNIUS_CH3_SUBZONE             */          VSCP_EEPROM_END + 9,
    /* REG0_VILNIUS_IO0_ZONE                */          VSCP_EEPROM_END + 10,
    /* REG0_VILNIUS_IO0_SUBZONE             */          VSCP_EEPROM_END + 11,
    /* REG0_VILNIUS_IO1_ZONE                */          VSCP_EEPROM_END + 12,
    /* REG0_VILNIUS_IO1_SUBZONE             */          VSCP_EEPROM_END + 13,
    /* REG0_VILNIUS_CONTROL_MODULE          */          VSCP_EEPROM_END + 14,
    /* REG0_VILNIUS_CONTROL_CHANNEL0        */          VSCP_EEPROM_END + 15,
    /* REG0_VILNIUS_CONTROL_CHANNEL1        */          VSCP_EEPROM_END + 16,
    /* REG0_VILNIUS_CONTROL_CHANNEL2        */          VSCP_EEPROM_END + 17,
    /* REG0_VILNIUS_CONTROL_CHANNEL3        */          VSCP_EEPROM_END + 18,
    /* REG0_VILNIUS_AD_VALUE_CHANNEL0_MSB   */          0xff,
    /* REG0_VILNIUS_AD_VALUE_CHANNEL0_LSB   */          0xff,
    /* REG0_VILNIUS_AD_VALUE_CHANNEL1_MSB   */          0xff,
    /* REG0_VILNIUS_AD_VALUE_CHANNEL1_LSB   */          0xff,
    /* REG0_VILNIUS_AD_VALUE_CHANNEL2_MSB   */          0xff,
    /* REG0_VILNIUS_AD_VALUE_CHANNEL2_LSB   */          0xff,
    /* REG0_VILNIUS_AD_VALUE_CHANNEL3_MSB   */          0xff,
    /* REG0_VILNIUS_AD_VALUE_CHANNEL3_LSB   */          0xff,
    /* REG0_VILNIUS_AD_REPORT_INTERVAL_CHANNEL0_MSB*/   VSCP_EEPROM_END + 19,
    /* REG0_VILNIUS_AD_REPORT_INTERVAL_CHANNEL0_LSB*/   VSCP_EEPROM_END + 20,
    /* REG0_VILNIUS_AD_REPORT_INTERVAL_CHANNEL1_MSB*/   VSCP_EEPROM_END + 21,
    /* REG0_VILNIUS_AD_REPORT_INTERVAL_CHANNEL1_LSB*/   VSCP_EEPROM_END + 22,
    /* REG0_VILNIUS_AD_REPORT_INTERVAL_CHANNEL2_MSB*/   VSCP_EEPROM_END + 23,
    /* REG0_VILNIUS_AD_REPORT_INTERVAL_CHANNEL2_LSB*/   VSCP_EEPROM_END + 24,
    /* REG0_VILNIUS_AD_REPORT_INTERVAL_CHANNEL3_MSB*/   VSCP_EEPROM_END + 25,
    /* REG0_VILNIUS_AD_REPORT_INTERVAL_CHANNEL3_LSB*/   VSCP_EEPROM_END + 26,
    /* REG0_VILNIUS_ALARM_LOW_CHANNEL0_MSB  */          VSCP_EEPROM_END + 27,
    /* REG0_VILNIUS_ALARM_LOW_CHANNEL0_LSB  */          VSCP_EEPROM_END + 28,
    /* REG0_VILNIUS_ALARM_LOW_CHANNEL1_MSB  */          VSCP_EEPROM_END + 29,
    /* REG0_VILNIUS_ALARM_LOW_CHANNEL1_LSB  */          VSCP_EEPROM_END + 30,
    /* REG0_VILNIUS_ALARM_LOW_CHANNEL2_MSB  */          VSCP_EEPROM_END + 31,
    /* REG0_VILNIUS_ALARM_LOW_CHANNEL2_LSB  */          VSCP_EEPROM_END + 32,
    /* REG0_VILNIUS_ALARM_LOW_CHANNEL3_MSB  */          VSCP_EEPROM_END + 33,
    /* REG0_VILNIUS_ALARM_LOW_CHANNEL3_LSB  */          VSCP_EEPROM_END + 34,
    /* REG0_VILNIUS_ALARM_HIGH_CHANNEL0_MSB */          VSCP_EEPROM_END + 35,
    /* REG0_VILNIUS_ALARM_HIGH_CHANNEL0_LSB */          VSCP_EEPROM_END + 36,
    /* REG0_VILNIUS_ALARM_HIGH_CHANNEL1_MSB */          VSCP_EEPROM_END + 37,
    /* REG0_VILNIUS_ALARM_HIGH_CHANNEL1_LSB */          VSCP_EEPROM_END + 38,
    /* REG0_VILNIUS_ALARM_HIGH_CHANNEL2_MSB */          VSCP_EEPROM_END + 39,
    /* REG0_VILNIUS_ALARM_HIGH_CHANNEL2_LSB */          VSCP_EEPROM_END + 40,
    /* REG0_VILNIUS_ALARM_HIGH_CHANNEL3_MSB */          VSCP_EEPROM_END + 41,
    /* REG0_VILNIUS_ALARM_HIGH_CHANNEL3_LSB */          VSCP_EEPROM_END + 42,
    /* REG0_VILNIUS_HYSTERESIS_CH0_MSB      */          VSCP_EEPROM_END + 43,
    /* REG0_VILNIUS_HYSTERESIS_CH1_MSB      */          VSCP_EEPROM_END + 44,
    /* REG0_VILNIUS_HYSTERESIS_CH2_MSB      */          VSCP_EEPROM_END + 45,
    /* REG0_VILNIUS_HYSTERESIS_CH3_MSB      */          VSCP_EEPROM_END + 46,
    /* REG0_VILNIUS_MESURMENT_REPORT_INTERVAL_CH0_MSB */  VSCP_EEPROM_END + 47,
    /* REG0_VILNIUS_MESURMENT_REPORT_INTERVAL_CH0_LSB */  VSCP_EEPROM_END + 48,
    /* REG0_VILNIUS_MESURMENT_REPORT_INTERVAL_CH1_MSB */  VSCP_EEPROM_END + 49,
    /* REG0_VILNIUS_MESURMENT_REPORT_INTERVAL_CH1_LSB */  VSCP_EEPROM_END + 50,
    /* REG0_VILNIUS_MESURMENT_REPORT_INTERVAL_CH2_MSB */  VSCP_EEPROM_END + 51,
    /* REG0_VILNIUS_MESURMENT_REPORT_INTERVAL_CH2_LSB */  VSCP_EEPROM_END + 52,
    /* REG0_VILNIUS_MESURMENT_REPORT_INTERVAL_CH3_MSB */  VSCP_EEPROM_END + 53,
    /* REG0_VILNIUS_MESURMENT_REPORT_INTERVAL_CH3_MSB */  VSCP_EEPROM_END + 54,
    /* REG0_VILNIUS_ABSOLUT_LOW_CHANNEL0_MSB    */      VSCP_EEPROM_END + 55,
    /* REG0_VILNIUS_ABSOLUT_LOW_CHANNEL0_LSB    */      VSCP_EEPROM_END + 56,
    /* REG0_VILNIUS_ABSOLUT_LOW_CHANNEL1_MSB    */      VSCP_EEPROM_END + 57,
    /* REG0_VILNIUS_ABSOLUT_LOW_CHANNEL1_LSB    */      VSCP_EEPROM_END + 58,
    /* REG0_VILNIUS_ABSOLUT_LOW_CHANNEL2_MSB    */      VSCP_EEPROM_END + 59,
    /* REG0_VILNIUS_ABSOLUT_LOW_CHANNEL2_LSB    */      VSCP_EEPROM_END + 60,
    /* REG0_VILNIUS_ABSOLUT_LOW_CHANNEL3_MSB    */      VSCP_EEPROM_END + 61,
    /* REG0_VILNIUS_ABSOLUT_LOW_CHANNEL3_LSB    */      VSCP_EEPROM_END + 62,
    /* REG0_VILNIUS_ABSOLUT_HIGH_CHANNEL0_MSB   */      VSCP_EEPROM_END + 63,
    /* REG0_VILNIUS_ABSOLUT_HIGH_CHANNEL0_LSB   */      VSCP_EEPROM_END + 64,
    /* REG0_VILNIUS_ABSOLUT_HIGH_CHANNEL1_MSB   */      VSCP_EEPROM_END + 65,
    /* REG0_VILNIUS_ABSOLUT_HIGH_CHANNEL1_LSB   */      VSCP_EEPROM_END + 66,
    /* REG0_VILNIUS_ABSOLUT_HIGH_CHANNEL2_MSB   */      VSCP_EEPROM_END + 67,
    /* REG0_VILNIUS_ABSOLUT_HIGH_CHANNEL2_LSB   */      VSCP_EEPROM_END + 68,
    /* REG0_VILNIUS_ABSOLUT_HIGH_CHANNEL3_MSB   */      VSCP_EEPROM_END + 69,
    /* REG0_VILNIUS_ABSOLUT_HIGH_CHANNEL3_LSB   */      VSCP_EEPROM_END + 70,
    /* REG0_VILNIUS_CONTROL_IO                  */      VSCP_EEPROM_END + 71,
    /* REG0_VILNIUS_IO_STATE                    */      0xff,
};

// This table translates registers in page 1 to EEPROM locations
const uint8_t reg2eeprom_pg1[] = {
    /* REG1_VILNIUS_LINEARIZATION_EVENT_SETTING_CH0 */  VSCP_EEPROM_END + 72,
    /* REG1_VILNIUS_LINEARIZATION_EVENT_CLASS_CH0   */  VSCP_EEPROM_END + 73,
    /* REG1_VILNIUS_LINEARIZATION_EVENT_TYPE_CH0    */  VSCP_EEPROM_END + 74,
    /* REG1_VILNIUS_LINEARIZATION_EVENT_SETTING_CH1 */  VSCP_EEPROM_END + 75,
    /* REG1_VILNIUS_LINEARIZATION_EVENT_CLASS_CH1   */  VSCP_EEPROM_END + 76,
    /* REG1_VILNIUS_LINEARIZATION_EVENT_TYPE_CH1    */  VSCP_EEPROM_END + 77,
    /* REG1_VILNIUS_LINEARIZATION_EVENT_SETTING_CH2 */  VSCP_EEPROM_END + 78,
    /* REG1_VILNIUS_LINEARIZATION_EVENT_CLASS_CH2   */  VSCP_EEPROM_END + 79,
    /* REG1_VILNIUS_LINEARIZATION_EVENT_TYPE_CH2    */  VSCP_EEPROM_END + 80,
    /* REG1_VILNIUS_LINEARIZATION_EVENT_SETTING_CH3 */  VSCP_EEPROM_END + 81,
    /* REG1_VILNIUS_LINEARIZATION_EVENT_CLASS_CH3   */  VSCP_EEPROM_END + 81,
    /* REG1_VILNIUS_LINEARIZATION_EVENT_TYPE_CH3    */  VSCP_EEPROM_END + 82,
    /* REG1_VILNIUS_CH0_LINEARIZATION_K_0           */  VSCP_EEPROM_END + 83,
    /* REG1_VILNIUS_CH0_LINEARIZATION_K_1           */  VSCP_EEPROM_END + 84,
    /* REG1_VILNIUS_CH0_LINEARIZATION_K_2           */  VSCP_EEPROM_END + 85,
    /* REG1_VILNIUS_CH0_LINEARIZATION_K_3           */  VSCP_EEPROM_END + 86,
    /* REG1_VILNIUS_CH1_LINEARIZATION_K_0           */  VSCP_EEPROM_END + 87,
    /* REG1_VILNIUS_CH1_LINEARIZATION_K_1           */  VSCP_EEPROM_END + 88,
    /* REG1_VILNIUS_CH1_LINEARIZATION_K_2           */  VSCP_EEPROM_END + 89,
    /* REG1_VILNIUS_CH1_LINEARIZATION_K_3           */  VSCP_EEPROM_END + 90,
    /* REG1_VILNIUS_CH2_LINEARIZATION_K_0           */  VSCP_EEPROM_END + 91,
    /* REG1_VILNIUS_CH2_LINEARIZATION_K_1           */  VSCP_EEPROM_END + 92,
    /* REG1_VILNIUS_CH2_LINEARIZATION_K_2           */  VSCP_EEPROM_END + 93,
    /* REG1_VILNIUS_CH2_LINEARIZATION_K_3           */  VSCP_EEPROM_END + 94,
    /* REG1_VILNIUS_CH3_LINEARIZATION_K_0           */  VSCP_EEPROM_END + 95,
    /* REG1_VILNIUS_CH3_LINEARIZATION_K_1           */  VSCP_EEPROM_END + 96,
    /* REG1_VILNIUS_CH3_LINEARIZATION_K_2           */  VSCP_EEPROM_END + 97,
    /* REG1_VILNIUS_CH3_LINEARIZATION_K_3           */  VSCP_EEPROM_END + 98,
    /* REG1_VILNIUS_CH0_LINEARIZATION_M_0           */  VSCP_EEPROM_END + 99,
    /* REG1_VILNIUS_CH0_LINEARIZATION_M_1           */  VSCP_EEPROM_END + 100,
    /* REG1_VILNIUS_CH0_LINEARIZATION_M_2           */  VSCP_EEPROM_END + 101,
    /* REG1_VILNIUS_CH0_LINEARIZATION_M_3           */  VSCP_EEPROM_END + 102,
    /* REG1_VILNIUS_CH1_LINEARIZATION_M_0           */  VSCP_EEPROM_END + 103,
    /* REG1_VILNIUS_CH1_LINEARIZATION_M_1           */  VSCP_EEPROM_END + 104,
    /* REG1_VILNIUS_CH1_LINEARIZATION_M_2           */  VSCP_EEPROM_END + 105,
    /* REG1_VILNIUS_CH1_LINEARIZATION_M_3           */  VSCP_EEPROM_END + 106,
    /* REG1_VILNIUS_CH2_LINEARIZATION_M_0           */  VSCP_EEPROM_END + 107,
    /* REG1_VILNIUS_CH2_LINEARIZATION_M_1           */  VSCP_EEPROM_END + 108,
    /* REG1_VILNIUS_CH2_LINEARIZATION_M_2           */  VSCP_EEPROM_END + 109,
    /* REG1_VILNIUS_CH2_LINEARIZATION_M_3           */  VSCP_EEPROM_END + 110,
    /* REG1_VILNIUS_CH3_LINEARIZATION_M_0           */  VSCP_EEPROM_END + 111,
    /* REG1_VILNIUS_CH3_LINEARIZATION_M_1           */  VSCP_EEPROM_END + 112,
    /* REG1_VILNIUS_CH3_LINEARIZATION_M_2           */  VSCP_EEPROM_END + 113,
    /* REG1_VILNIUS_CH3_LINEARIZATION_M_3           */  VSCP_EEPROM_END + 114,
};

#define DECISION_MATRIX_EEPROM_START                    VSCP_EEPROM_END + 115     // always one after above

///////////////////////////////////////////////////////////////////////////////
// Isr() 	- Interrupt Service Routine
//      	- Services Timer0 Overflow
//      	- Services GP3 Pin Change
//////////////////////////////////////////////////////////////////////////////
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
void main()
{
    init();         // Initialize Micro controller
    
    // Check VSCP persistent storage and
    // restore if needed
    if ( !vscp_check_pstorage() ) {

        // Spoiled or not initialized - reinitialize
        init_app_eeprom();

    }
    
    // Initialize data
    init_app_ram();
    
    // Initialize the VSCP functionality
    vscp_init();    
    
    // Set DM filters
    calculateSetFilterMask();
            
    while ( 1 ) {   // Loop Forever

        ClrWdt();   // Feed the dog

        if ( ( vscp_initbtncnt > 2500 ) &&
             ( VSCP_STATE_INIT != vscp_node_state ) ) {

            // Init. button pressed
            vscp_nickname = VSCP_ADDRESS_FREE;
            eeprom_write( VSCP_EEPROM_NICKNAME, VSCP_ADDRESS_FREE );
            vscp_init();
            
        }

        // Check for a valid  event
        vscp_imsg.flags = 0;
        vscp_getEvent();

        switch ( vscp_node_state ) {

            case VSCP_STATE_STARTUP: // Cold/warm reset

                // Get nickname from EEPROM
                if (VSCP_ADDRESS_FREE == vscp_nickname) {
                    // new on segment need a nickname
                    vscp_node_state = VSCP_STATE_INIT;
                } 
                else {
                    // been here before - go on
                    vscp_node_state = VSCP_STATE_ACTIVE;
                    vscp_goActiveState();
                }
                break;

            case VSCP_STATE_INIT: // Assigning nickname
                vscp_handleProbeState();
                break;

            case VSCP_STATE_PREACTIVE:  // Waiting for host initialization
                vscp_goActiveState();
                break;

            case VSCP_STATE_ACTIVE:     // The normal state

                // Check for incoming event?
                if (vscp_imsg.flags & VSCP_VALID_MSG) {

                    if ( VSCP_CLASS1_PROTOCOL == vscp_imsg.vscp_class  ) {

                        // Handle protocol event
                        vscp_handleProtocolEvent();

                    }
                    else {    

                        doDM();
                        
                        // Check for sync request
                        if ( ( VSCP_CLASS1_CONTROL == vscp_imsg.vscp_class ) &&
                                ( VSCP_TYPE_CONTROL_SYNC == vscp_imsg.vscp_type ) ) {
                            
                            handleSyncRequest( vscp_imsg.data[ 0 ], 
                                                    vscp_imsg.data[ 1 ], 
                                                    vscp_imsg.data[ 2 ] );
                            
                        }
                        
                    }
                    
                }               
                break;

            case VSCP_STATE_ERROR: // Everything is *very* *very* bad.
                vscp_error();
                break;

            default: // Should not be here...
                vscp_node_state = VSCP_STATE_STARTUP;
                break;

        }

        // do a measurement if needed
        if ( measurement_clock_sec > 1000 ) {

            measurement_clock_sec = 0;
 
            // Do VSCP one second jobs
            vscp_doOneSecondWork();

            if ( VSCP_STATE_ACTIVE == vscp_node_state ) {
                // Do VSCP one second jobs
                doApplicationOneSecondWork();
            }

        }

        // Timekeeping
        if ( seconds > 59 ) {

            seconds = 0;
            minutes++;

            if ( minutes > 59 ) {
                minutes = 0;
                hours++;
            }

            if ( hours > 23 ) hours = 0;

        }

        // Do loop work
        doWork();

    } // while
}

///////////////////////////////////////////////////////////////////////////////
// Init. - Initialisation Routine
//  

void init()
{   
    //uint8_t msgdata[ 8 ];

    // Initialise the uP
    
    // PORTA
    // RA0/AN0 - input
    // RA1/AN1 - input
    // RA2/AN2 - input
    // RA3/AN3 - input
    // RA4 input (VCAP for PIC18F26K80))
    TRISA = 0x1F;
    
    // RC0 - Input  - Init. button
    // RC1 - Output - Status LED - Default off
    // RC2 - Output - Not used = output..
    // RC3 - Output - Not used = output.
    // RC4 - Input - I/O channel 0.
    // RC5 - Input - I/O channel 1.
    // RC6 - Output - Not used = output.
    // RC7 - Output - Not used = output.
    TRISC = 0b00000001;
    PORTC = 0x00;   // Default off

    OpenTimer0( TIMER_INT_ON & T0_16BIT & T0_SOURCE_INT & T0_PS_1_8 );
    WriteTimer0( TIMER0_RELOAD_VALUE );
    
#if defined(_18F2580)     
    OpenADC(ADC_FOSC_64 & ADC_RIGHT_JUST & ADC_20_TAD,
            ADC_CH0 & ADC_INT_ON & ADC_11ANA &
            ADC_VREFPLUS_VDD & ADC_VREFMINUS_VSS,
            15);
#else if defined(_18F25K80) || defined(_18F26K80) || defined(_18F45K80) || defined(_18F46K80) || defined(_18F65K80) || defined(_18F66K80)
    OpenADC(ADC_FOSC_64 & ADC_RIGHT_JUST & ADC_20_TAD,
                ADC_CH0 & ADC_INT_ON,
                15);
#endif   

    // Initialize CAN
    ECANInitialize();

    // Must be in config. mode to change many of settings.
    //ECANSetOperationMode(ECAN_OP_MODE_CONFIG);

    // Return to Normal mode to communicate.
    //ECANSetOperationMode(ECAN_OP_MODE_NORMAL);

    /*
        msgdata[ 0 ] = 1;
            msgdata[ 1 ] = 2;
            msgdata[ 2 ] = 3;
            msgdata[ 3 ] = 4;

            if ( vscp18f_sendMsg( 0x123,  msgdata, 4, CAN_TX_PRIORITY_0 & CAN_TX_XTD_FRAME & CAN_TX_NO_RTR_FRAME ) ) {
                    ;
            }

     */
        
    // Enable global interrupt
    INTCONbits.GIE = 1;

    ConvertADC();

    return;
}

///////////////////////////////////////////////////////////////////////////////
// init_app_ram
//

void init_app_ram( void )
{    
    measurement_clock_sec = 0;      // start a new measurement cycle
    
    seconds = 0;
    minutes = 0;
    hours = 0;
    
    memset( analog_value, 0, sizeof( analog_value ) );
    
    memset( bLowAlarm, 0, sizeof( bLowAlarm ) );
    memset( bHighAlarm, 0, sizeof( bHighAlarm ) );
    
    memset( valueReports, 0, sizeof( valueReports ) );
    memset( measurementReports, 0, sizeof( measurementReports ) );
    
    IOsavebit0 = FALSE;
    IOsavebit1 = FALSE;
}

///////////////////////////////////////////////////////////////////////////////
// init_app_eeprom
//
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

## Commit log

2015-06-15 Initial checkin
    [bom.ods, smdad001.brd, smdad001.sch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]
2015-11-14 AKHE VCAP decoupled from VCC
    [vilnius_rev_c.brd, vilnius_rev_c.sch]
2015-12-07 Main functionality in place
    [vilnius_rev_c.brd, vilnius_rev_c.sch]
2015-12-08 I/O event handling in place
    [vilnius_rev_c.brd, vilnius_rev_c.sch]
2015-12-17 Changed copyright info in headers so it is correct
    [main.c, vilnius.h]
2016-04-04 Changed value of C14 to 10uF
    [vilnius_rev_c.brd, vilnius_rev_c.sch]
2016-04-19 RA4 set to input to prevent collision with VCAP circuits in PIC18F2580. Brown out raised to maximum (3V & 4.6V). Valuable input from Anders Forsgren, AJE Electronics AB.
    [main.c]
2024-04-19 DM on page 3 in header is wrong, should be 2
    [vilnius.h]

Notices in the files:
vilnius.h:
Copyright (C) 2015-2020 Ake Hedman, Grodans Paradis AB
